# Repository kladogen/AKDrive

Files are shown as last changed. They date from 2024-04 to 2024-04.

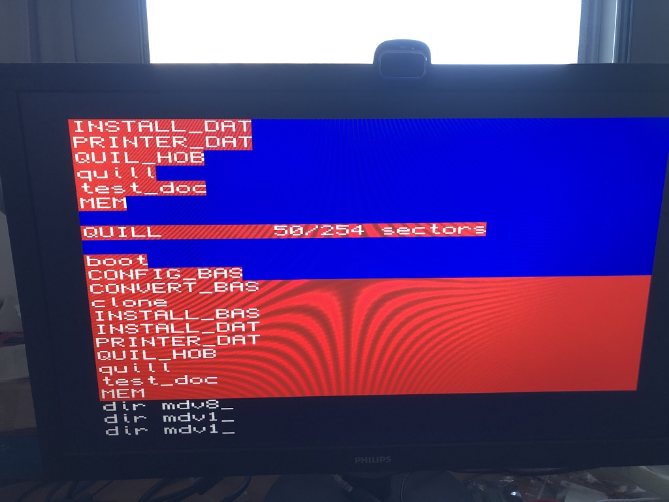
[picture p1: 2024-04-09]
Images/IMG_2267.JPG

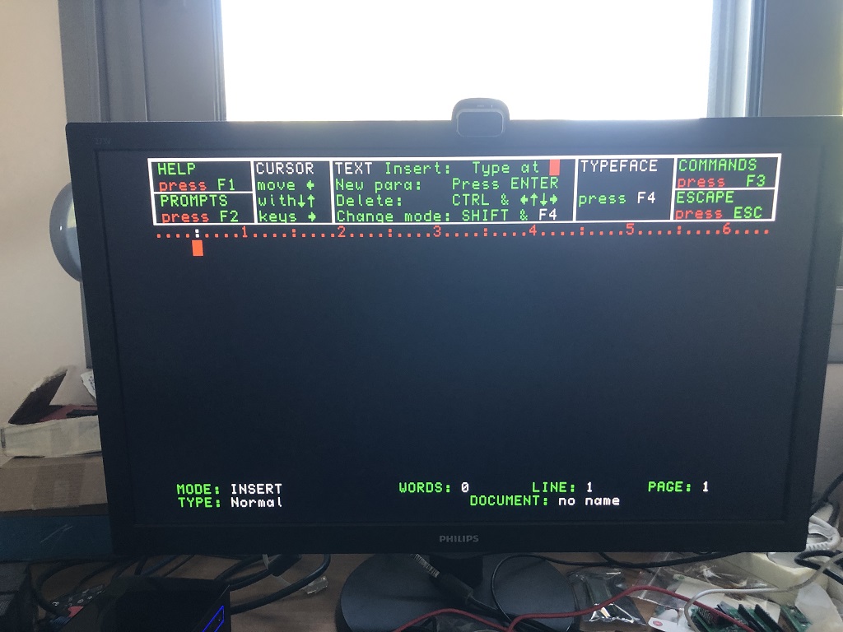
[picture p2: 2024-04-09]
Images/IMG_2269.JPG

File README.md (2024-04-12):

# AKDrive
<b>Sinclair QL Microdrive Emulator</b>

This an external microdrive emulator for the sinclair QL. It utilizes a raspberry pico to do the emulation and an SD card to hold the images. It has the ability to enable or disable the hardware microdrives with the addition to the QL of two small boards between the QL and the hardware microdrives that are controlled from the emulator. In this way you get to keep your hardware microdrives and use them whenever needed. 

<b>The emulator can read from MDV images, write to them, format them and also create new formated MDVs</b>.

Also, a QL Basic application is available in mdv8_ that can be used to select directly from the QL the image to load in each drive (mdv1_ to mdv7_).

<b>All mdv images are optimized by the emulator to load with maximum speed.</b>

Four buttons are available (previous, next, enter, back) to navigate the menu and an OLED screen to display the menu.
The board design is available to download and also the UDF to program the pico. In order to avoid people selling this project on ebay I will provide one license key to any one that will request it. When you use it for the first time, a file named SerNum.txt will be created in the SD card. You just send me this number and I will reply with the key that you will place in a file named lic.txt.

In folder PCB_43 you will find the KiCad files of the PCB rev4.3. In folder QL_MDV_Control you will find the KiCad files for the boards used to control the hardware microdrives.

Enjoy!

Youtube video : https://www.youtube.com/watch?v=eIUnk80rTSo (Greek)

Enclosure : https://www.thingiverse.com/thing:6572931

I specialy want to thank for their help Nikos Doukas, Petar Pandurov and Anestis Koutsoudis who designed the enclosure!

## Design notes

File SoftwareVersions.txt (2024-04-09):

Software Version Changes and improvements
// 23.10.1 : Initial version
// 23.10.2 : Changed the OLED library and added support for multiple OLED types and chips. 
//           Added the OLED.cfg in the SD so the user can modify the OLED display size. 
//           The chip is detected automaticaly by the library.
//           Beware : non-void functions that don't return something CRASH!!!
// 23.10.3 : Changed SaveSectorDataRecordToMDV to store sector data in the .omd file when 
//           TurboModeOn. Otherwise save does not work since it saves to .mdv sectors and 
//           reads from .omd sectors. Also the .mdv is destroyed because the sectors used
//           different!
//           The .OMD files, in order to remain optimized need to be re-optimized every 
//           time data is written in them, however since the QL does not maintain a
//           timestamp on files this needs to managed by the AK-Drive. One solution is to
//           maintain a list of modified files and re-optimize them at startup and the other
//           is to reoptimize them anyway at startup. This can be done by deleting the .mdv
//           files, renaming the .omd to mdv and then proceeding with startup.
// 23.10.4 : Changed connection of data lines to the QL. Instead of using the 74LS125 buffer
//           we are now using 2 BAT43 diodes and having the lines pulled up when at input
//           state (QL sending data) and as high power (8mA) outputs when sending data to
//           the QL (QL receiving data).
//           Also the SD card is directly connected to the pico without the extra board.
// 23.11.1 : Added support for both the old and new board. Also added a "selection efect"
//           when the user makes a selection in a menu.
//           The BOARD_VERSION define is used to compile the correct version of the firmware
//           for the target board.
//           Version 1: the fist board with the 74ls125 chip
//           Version 2: the second version with the BAT43 diodes.
// 23.11.2 : Added (c) notice.
//           Also added the Default Drive Offset selection in settings. This is usefull when
//           the number of hardware drive on the QL are more or less than 2.
//           Added the board version in txt configuration file named BoardVersion.txt. In this way
//           the same pico can be used with old an new boards by just changing the configuration 
//           in the file. The default board version is in the BOARD_VERSION define. Eventually it
//           needs to be changed to 2 when new boards get picos.
// 23.11.3 : Fixed bug the prohibited writing to AK-Drive when turbo mode was selected.
//           Changed button press timings so menu and file selection is faster.
//           Added the avility to break out of the menu if the drive is used from the QL
//           Added autoload of the first image found when the user changes the used images from the
//           QL via the runme application. Aslo fixed bug that made AK-Drive show instead of mdv8_
//           contents the previously loaded mdv.
// 23.11.4 : Added dynamic finding of MDVIMAGES file first sector. Added check for corruption of AK-Drive
//           image and message to the user.
// 23.12.1 : Fixed bug that did not delete old OMD files when an existing MDV was formated.
//           Also added a file in the formated MDV mentioning AKDrive to make happy Minerva with ToolKitII
//           since otherwise ToolkitII did not show the formated MDV.
// 24.01.1 : Changed default BoardVersion to 2
//           Added support for Hardware Microdrives control (mdv_control board). 
//           This is done through an addon board in the QL. Each hardware microdrive is connected through 
//           this addon board that is controlled from the AK-Drive.
//           The board enables the hardware drive by connecting through a bus driver the Clock, CommsIn and CommsOut
//           of the microdrive to the QL bus. 
//           If the drive is disabled CommsIN is directly connected to CommsOut and the microdrive's Clock, CommsIn and
//           CommsOut disconnected from the bus.
// 24.02.2 : Added support for small screen 128x32. Fixed bug in menu selection when going to previous page.

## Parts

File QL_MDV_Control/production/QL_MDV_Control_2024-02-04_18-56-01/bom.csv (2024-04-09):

Designator | Footprint | Quantity | Value | LCSC Part #
C1, C2 | CAPCP6032X280N | 2 | C_Polarized | 2312
J1-TOMDV1 | PinHeader_1x07_P2.54mm_Vertical | 1 | Conn_01x07_Pin
J2 | PinHeader_1x01_P2.54mm_Vertical | 1 | Conn_01x01
J2-TOQL1 | PinHeader_1x07_P2.54mm_Vertical | 1 | Conn_01x07_Socket
R1, R2 | 0805 | 2 | 10K | CRG0805-R-103JT
U1 | SOIC-14_3.9x8.7mm_P1.27mm | 1 | 74HCT04 | C513511
U2 | SOIC-14_3.9x8.7mm_P1.27mm | 1 | 74LS125 | C3754826
U3 | SOT-89-3 | 1 | AMS1117-5.0 | C880753

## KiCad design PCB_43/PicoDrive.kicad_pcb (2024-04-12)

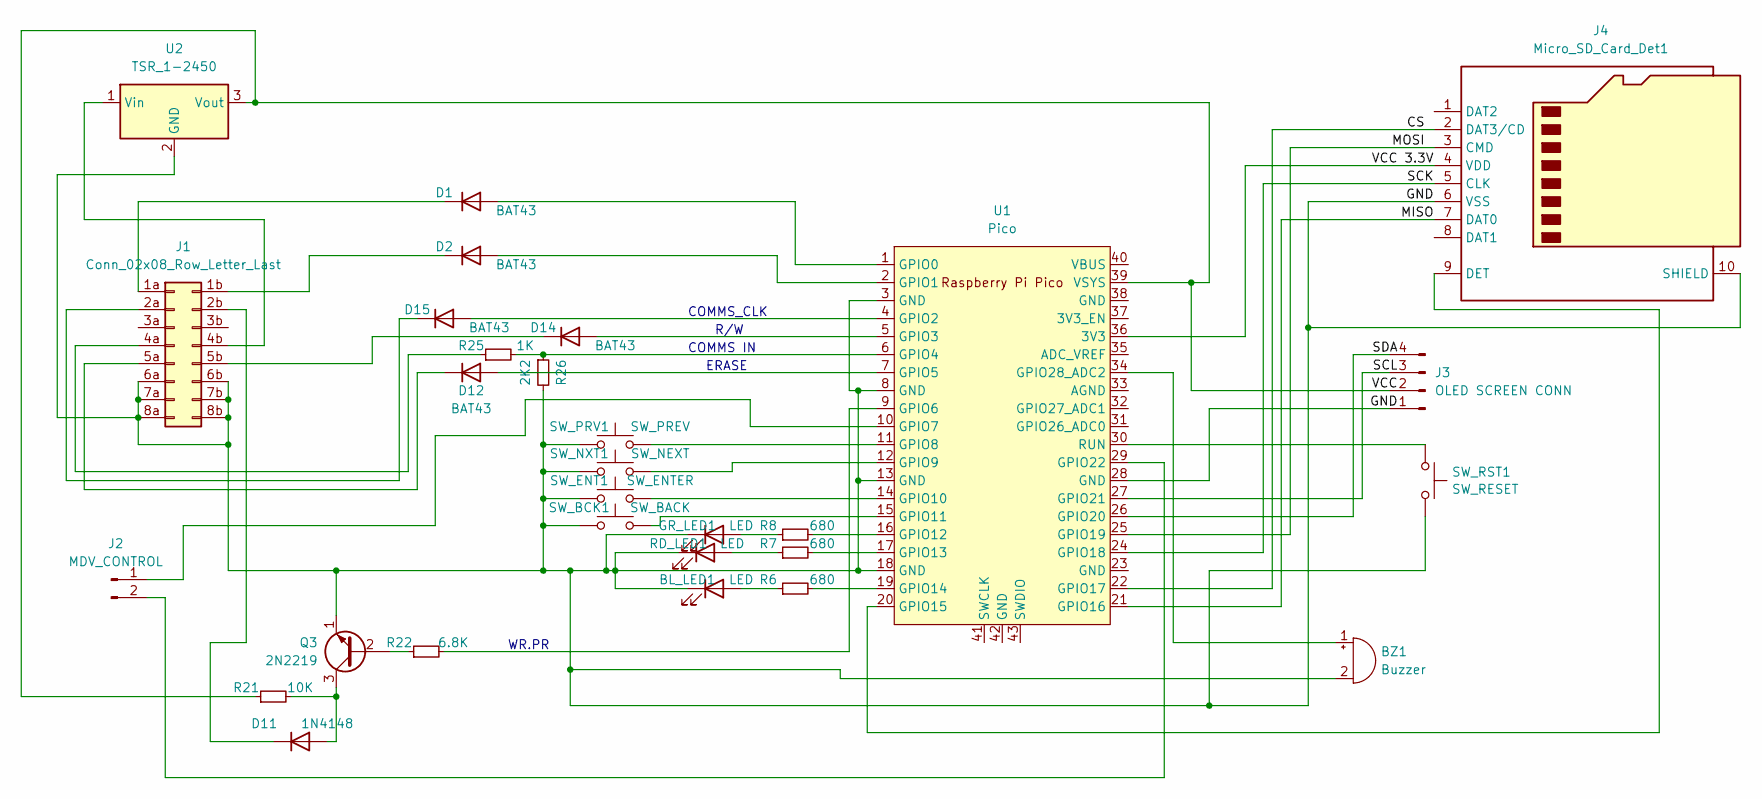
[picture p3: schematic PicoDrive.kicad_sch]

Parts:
BL_LED1: LED; LED_D3.0mm
BZ1: Buzzer; Buzzer_12x9.5RM7.6
D1, D2, D12, D14, D15: BAT43; D_DO-35_SOD27_P7.62mm_Horizontal
D11: 1N4148; D_DO-35_SOD27_P7.62mm_Horizontal
GR_LED1: LED; LED_D3.0mm
J1: Conn_02x08_Row_Letter_Last; PinHeader_2x08_P2.54mm_Vertical_letters
J2: MDV_CONTROL; PinHeader_1x02_P2.54mm_Vertical
J3: OLED SCREEN CONN; PinHeader_1x04_P2.54mm_Vertical
J4: Micro_SD_Card_Det1; MicroSD_Card-micro_socket_A_AliExpress
Q3: 2N2219; TO-39-3
R6, R7, R8: 680; R_Axial_DIN0204_L3.6mm_D1.6mm_P7.62mm_Horizontal
R21: 10K; R_Axial_DIN0204_L3.6mm_D1.6mm_P7.62mm_Horizontal
R22: 6.8K; R_Axial_DIN0204_L3.6mm_D1.6mm_P7.62mm_Horizontal
R25: 1K; R_Axial_DIN0204_L3.6mm_D1.6mm_P7.62mm_Horizontal
R26: 2K2; R_Axial_DIN0204_L3.6mm_D1.6mm_P7.62mm_Horizontal
RD_LED1: LED; LED_D3.0mm
SW_BCK1: SW_BACK; SW_PUSH_6mm
SW_ENT1: SW_ENTER; SW_PUSH_6mm
SW_NXT1: SW_NEXT; SW_PUSH_6mm
SW_PRV1: SW_PREV; SW_PUSH_6mm
SW_RST1: SW_RESET; SW_Tactile_SPST_Angled_PTS645Vx83-2LFS
U1: Pico; RPi_Pico_SMD_TH
U2: TSR_1-2450; Converter_DCDC_TRACO_TSR-1_THT

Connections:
/CS: J4.2 (DAT3/CD), U1.22 (GPIO17)
/GND: BL_LED1.1 (K), BZ1.2 (+), GR_LED1.1 (K), J1.6a, J1.6b, J1.7a, J1.7b, J1.8a, J1.8b, J4.6 (VSS), J4.10 (SHIELD), Q3.1 (E), R26.2, RD_LED1.1 (K), SW_BCK1.1, SW_ENT1.1, SW_NXT1.1, SW_PRV1.1, SW_RST1.2, U1.3 (GND), U1.8 (GND), U1.13 (GND), U1.18 (GND), U2.2 (GND)
/MISO: J4.7 (DAT0), U1.21 (GPIO16)
/MOSI: J4.3 (CMD), U1.25 (GPIO19)
/SCK: J4.5 (CLK), U1.24 (GPIO18)
/VCC 3.3V: J4.4 (VDD), U1.36 (3V3)
unnamed: BL_LED1.2 (A), R6.1
unnamed: BZ1.1 (-), U1.34 (GPIO28_ADC2)
unnamed: D1.2 (A), U1.1 (GPIO0)
unnamed: D1.1 (K), J1.1a
unnamed: D2.2 (A), U1.2 (GPIO1)
unnamed: D2.1 (K), J1.1b
unnamed: D11.2 (A), Q3.3 (C), R21.2
unnamed: D11.1 (K), J1.2b
unnamed: D12.2 (A), U1.7 (GPIO5)
unnamed: D12.1 (K), J1.5a
unnamed: D14.2 (A), U1.5 (GPIO3)
unnamed: D14.1 (K), J1.5b
unnamed: D15.2 (A), U1.4 (GPIO2)
unnamed: D15.1 (K), J1.2a
unnamed: GR_LED1.2 (A), R8.1
unnamed: J1.4a, R25.1
unnamed: J1.4b, U2.1 (Vin)
unnamed: J2.1, U1.10 (GPIO7)
unnamed: J2.2, U1.29 (GPIO22)
unnamed: J3.1, U1.28 (GND)
unnamed: J3.2, R21.1, U1.39 (VSYS), U2.3 (Vout)
unnamed: J3.3, U1.27 (GPIO21)
unnamed: J3.4, U1.26 (GPIO20)
unnamed: J4.9 (DET), U1.20 (GPIO15)
unnamed: Q3.2 (B), R22.1
unnamed: R7.1, RD_LED1.2 (A)
unnamed: R25.2, R26.1, U1.6 (GPIO4)
unnamed: R22.2, U1.9 (GPIO6)
unnamed: SW_PRV1.2, U1.11 (GPIO8)
unnamed: SW_NXT1.2, U1.12 (GPIO9)
unnamed: SW_ENT1.2, U1.14 (GPIO10)
unnamed: SW_BCK1.2, U1.15 (GPIO11)
unnamed: R8.2, U1.16 (GPIO12)
unnamed: R7.2, U1.17 (GPIO13)
unnamed: R6.2, U1.19 (GPIO14)
unnamed: SW_RST1.1, U1.30 (RUN)

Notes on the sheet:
R/W
ERASE
COMMS_CLK
COMMS IN
WR.PR

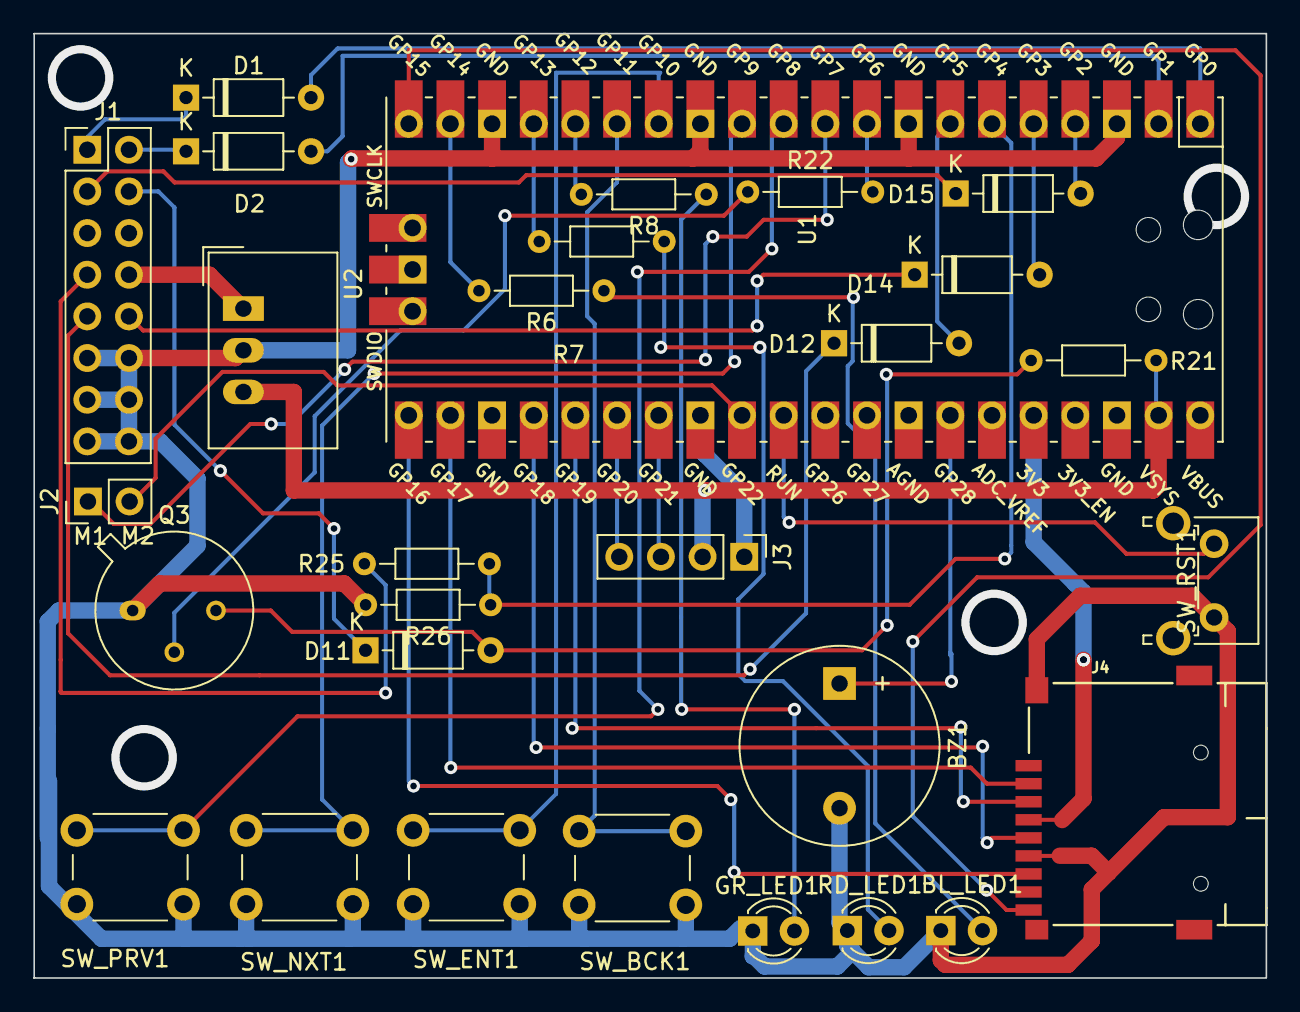
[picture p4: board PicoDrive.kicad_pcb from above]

Board: 2 copper layers, 75.2 x 57.6 mm, 29 parts (0 on the bottom side), 42 nets.

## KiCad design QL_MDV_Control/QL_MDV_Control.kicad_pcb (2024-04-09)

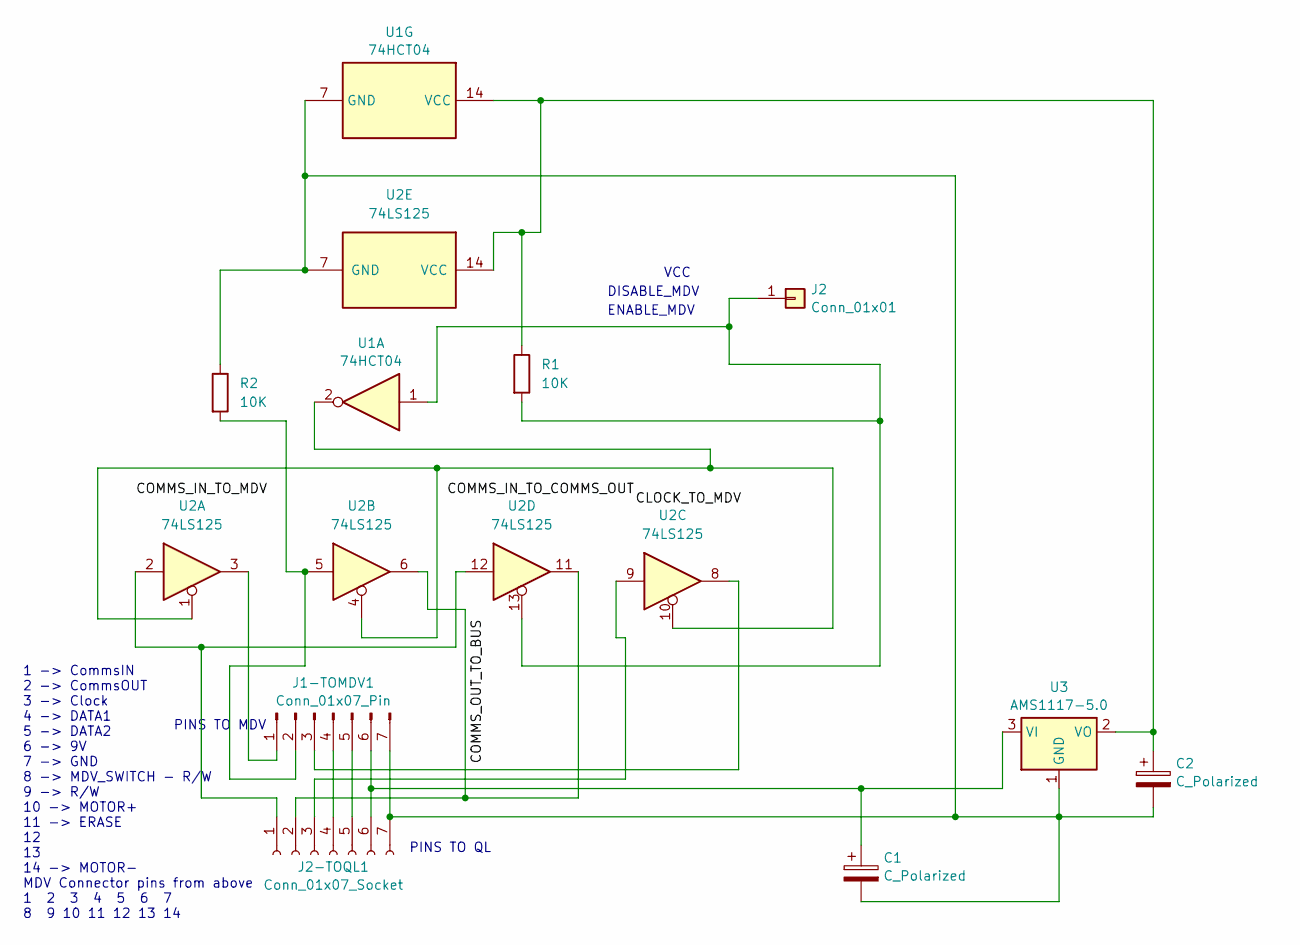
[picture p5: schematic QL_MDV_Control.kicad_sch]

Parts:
C1, C2: C_Polarized; CAPCP6032X280N; LCSC 2312
J1-TOMDV1: Conn_01x07_Pin; PinHeader_1x07_P2.54mm_Vertical
J2: Conn_01x01; PinHeader_1x01_P2.54mm_Vertical
J2-TOQL1: Conn_01x07_Socket; PinHeader_1x07_P2.54mm_Vertical
R1, R2: 10K; R_0805_2012Metric; LCSC CRG0805-R-103JT
U1: 74HCT04; SOIC-14_3.9x8.7mm_P1.27mm; LCSC C513511
U2: 74LS125; SOIC-14_3.9x8.7mm_P1.27mm; LCSC C133797
U3: AMS1117-5.0; SOT-89-3; LCSC C880753

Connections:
unnamed: J1-TOMDV1.1, U2.3
unnamed: J1-TOMDV1.2, R2.2, U2.5
unnamed: J1-TOMDV1.3, U2.8
unnamed: J1-TOMDV1.4, J2-TOQL1.4
unnamed: J1-TOMDV1.5, J2-TOQL1.5
unnamed: C1.1, J1-TOMDV1.6, J2-TOQL1.6, U3.3 (VI)
unnamed: C1.2, C2.2, J1-TOMDV1.7, J2-TOQL1.7, R2.1, U1.7 (GND), U2.7 (GND), U3.1 (GND)
unnamed: J2.1, R1.2, U1.1, U2.13
unnamed: J2-TOQL1.1, U2.2, U2.12
unnamed: J2-TOQL1.2, U2.6, U2.11
unnamed: J2-TOQL1.3, U2.9
unnamed: U1.2, U2.1, U2.4, U2.10
unnamed: C2.1, R1.1, U1.14 (VCC), U2.14 (VCC), U3.2 (VO)

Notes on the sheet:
VCC
ENABLE_MDV
DISABLE_MDV
PINS TO QL
PINS TO MDV
1 -> CommsIN 2 -> CommsOUT 3 -> Clock 4 -> DATA1 5 -> DATA2 6 -> 9V 7 -> GND 8 -> MDV_SWITCH - R/W 9 -> R/W 10 -> MOTOR+ 11 -> ERASE 12 13 14 -> MOTOR- MDV Connector pins from above 1 2 3 4 5 6 7 8 9 10 11 12 13 14

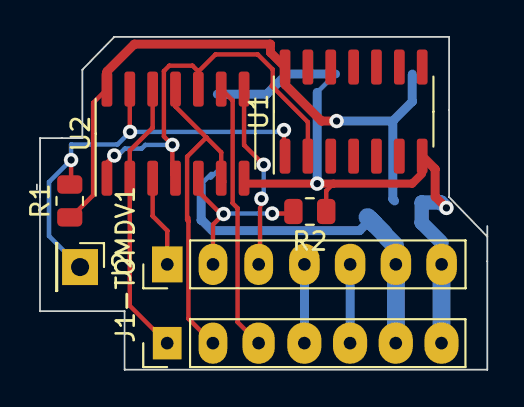
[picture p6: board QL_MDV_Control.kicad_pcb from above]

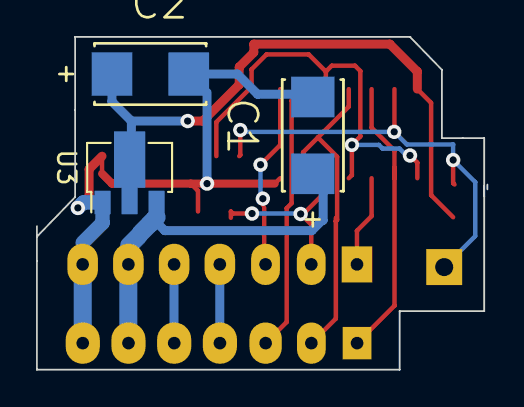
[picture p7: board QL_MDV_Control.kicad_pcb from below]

Board: 2 copper layers, 25.0 x 18.5 mm, 10 parts (3 on the bottom side), 13 nets.

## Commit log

2024-04-09 Changed dir name
    [PicoDrive-B_Cu.gbr, PicoDrive-B_Mask.gbr, PicoDrive-B_Paste.gbr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]
2024-04-12 Added to PCB a connector for MDV_Control boards
    [PicoDrive-B_Cu.gbr, PicoDrive-B_Mask.gbr, PicoDrive-B_Paste.gbr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]
2024-04-12 Info about new PCB version
